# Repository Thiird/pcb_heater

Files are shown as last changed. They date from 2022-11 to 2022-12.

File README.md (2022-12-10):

# PCB Heater

As part of my journey in embedded systems I try to learn new technologies with projects that fix inconveniences in my life. One such inconvenience is that during the winter time, especially in the evening, during long computer-session my feet get terribly cold. So cold that when I finally decide to get up they hurt during the first steps.

To fix this I decided to create a small assembly that houses a plate capable of heating up to a set temperature, on which I can comfortably rest my feet while I'm at my desk.

The assembly consists of three main parts, the heating element, a driver circuit and the wood structure on which everything mounts on.

# Hardware

The heating element is 30x30 cm^2 pcb that features a long copper track that acts as a resistor, and thus heats up when current flows through it.

The pcb is made of three 10x30 cm^2 aluminum pcb connected in series. The reason for using three smaller pcbs instead of a big one, given that the minimum order is 5 units, is that the cost of making five 10x30 cm^2 pcbs is way less than making 5 30x30 cm^2 pcbs. Each single pcb has a resistance of 2 Ohms and has a track 2.64 meters long.

The heating element is powered via a MOSFET used as switch with PWM by an ESP32-S2-MINI-2 MCU. The driver board has an OLED screen and some tactile buttons to let the user set the target temperature and monitor the whole assembly.

The main power source is a 12V-80W AC/DC brick, which feeds the heating PCB and the MCU part of the circuit via a 3.3V switching regulator.

Check bom file for full parts list.

The driver PCB is enclosed in a 3D printed case, which is screwed on the wood assembly.

# Firmware

The firmware for the ESP32 is written with the ESP-IDF framework and runs FreeRTOS.

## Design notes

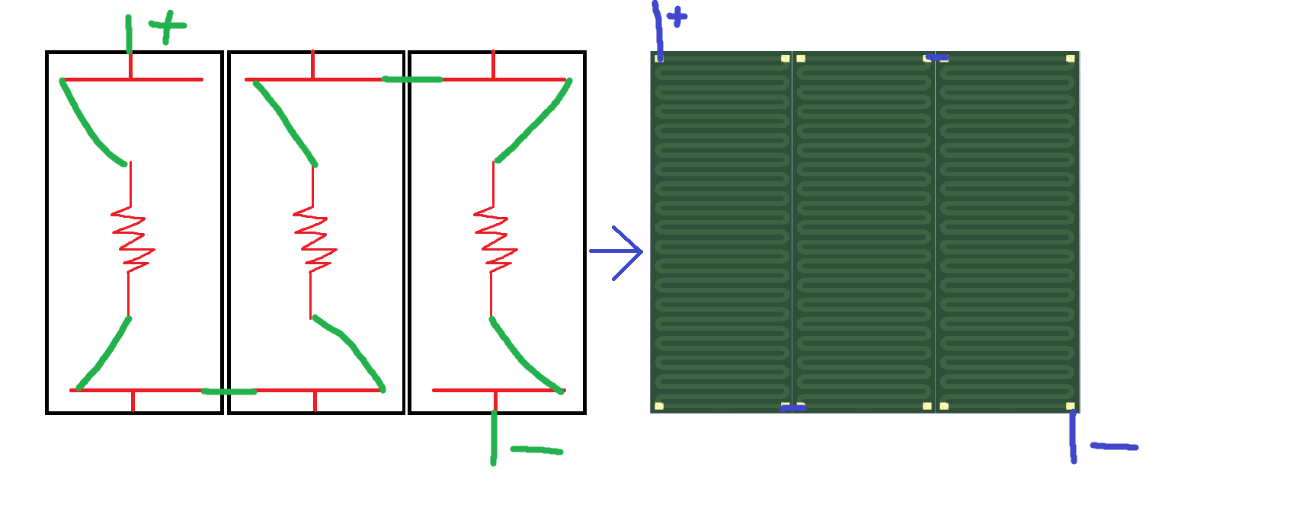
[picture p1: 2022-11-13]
HW/study/heater_schema.png

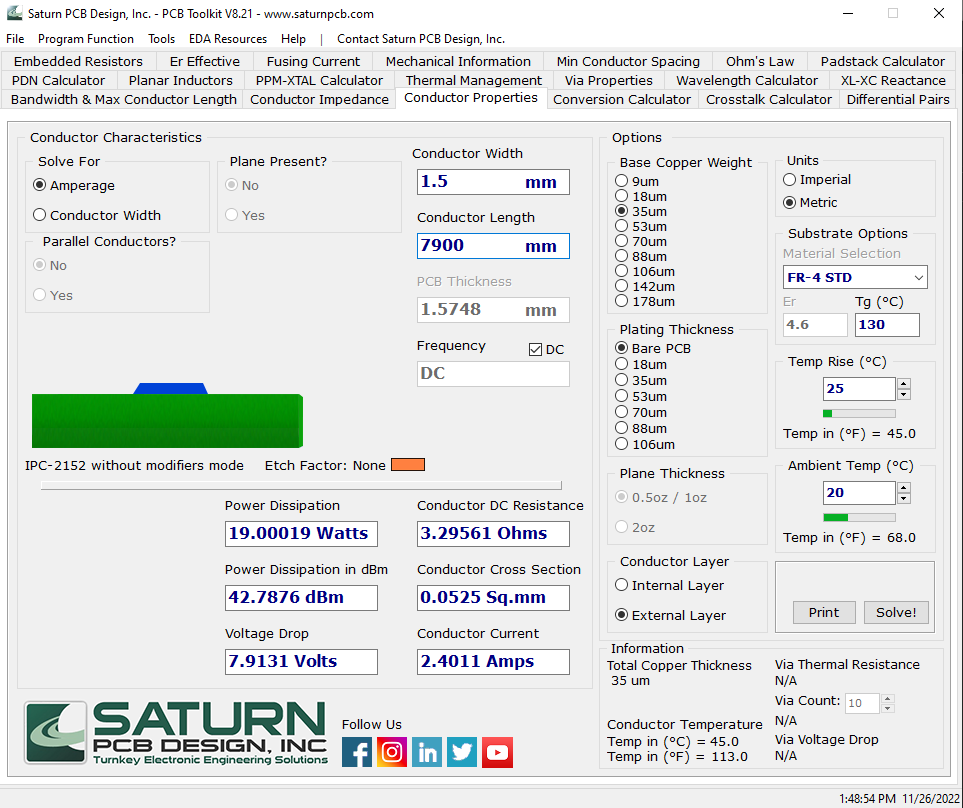
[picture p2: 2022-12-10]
HW/study/simulation.png

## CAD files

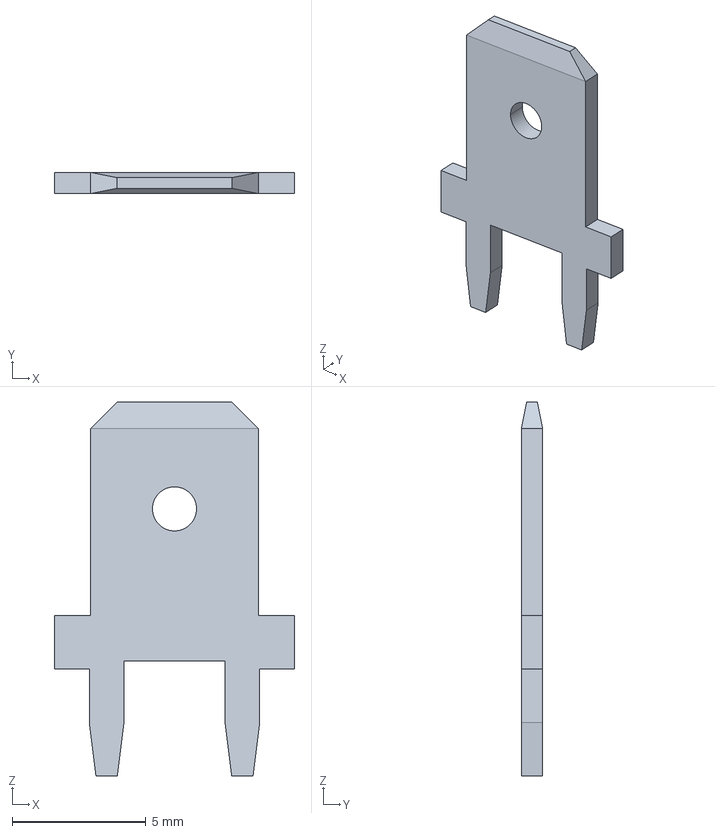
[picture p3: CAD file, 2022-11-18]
HW/footprints/3d/c-2376591-2-a-3d.stp
9.00 x 0.8 x 14.0 mm

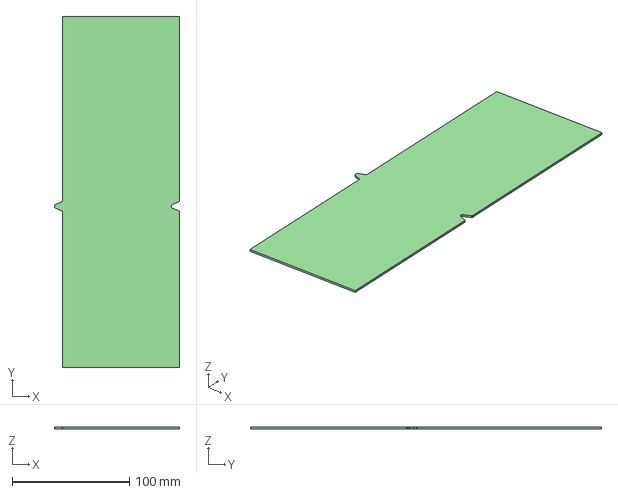
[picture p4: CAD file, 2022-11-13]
HW/pcb_heater_element.step
107.2 x 300.0 x 1.60 mm

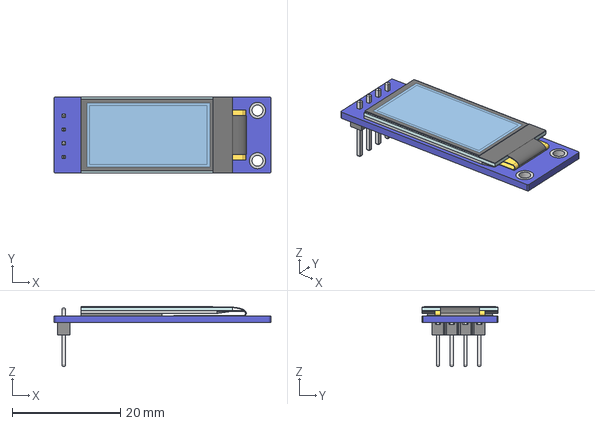
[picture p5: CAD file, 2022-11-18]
HW/footprints/3d/OLED_SSD1312_I2C_0.96.step
40.1 x 14.1 x 11.1 mm

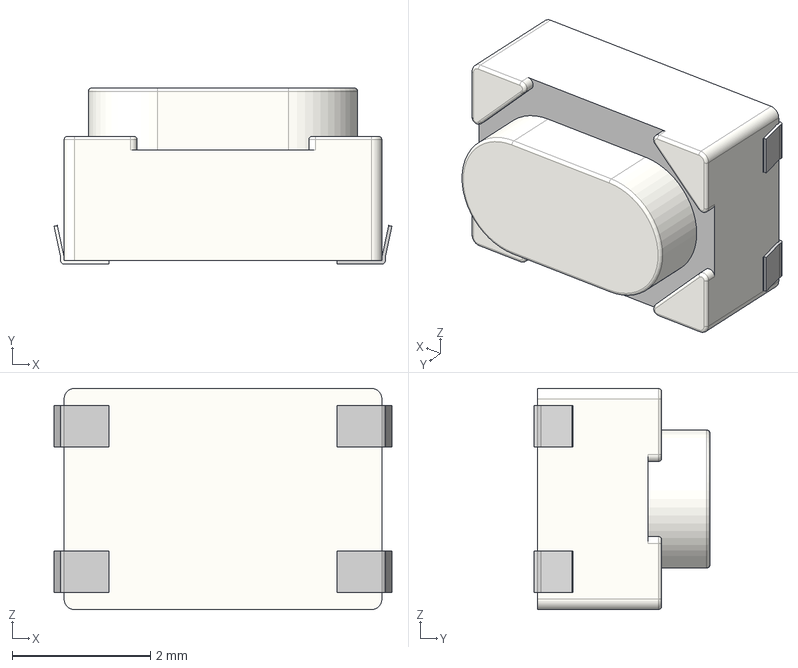
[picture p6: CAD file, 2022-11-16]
HW/footprints/3d/SKRPACE010 v4.step
4.89 x 2.55 x 3.20 mm

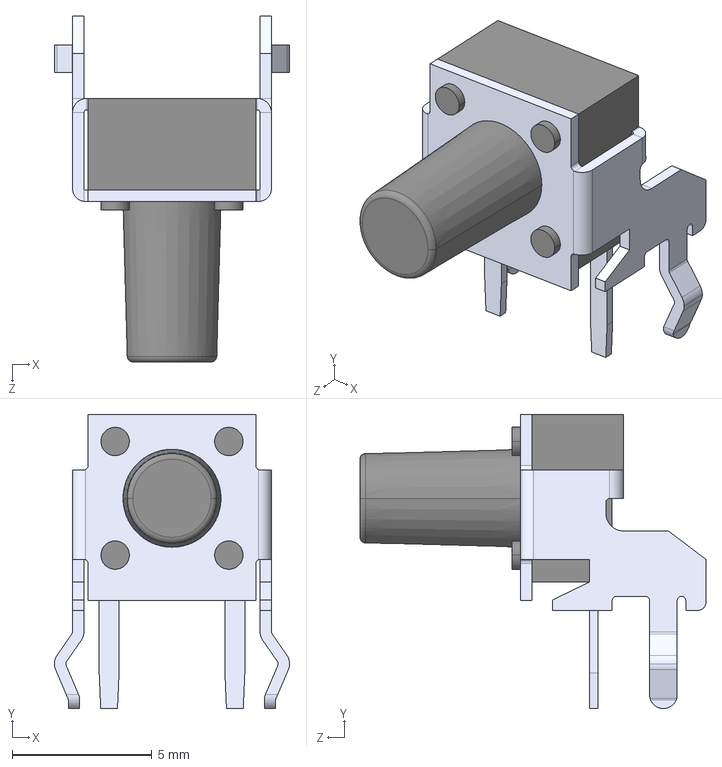
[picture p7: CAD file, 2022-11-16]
HW/footprints/3d/1-1825027-1.step
8.41 x 10.5 x 12.4 mm

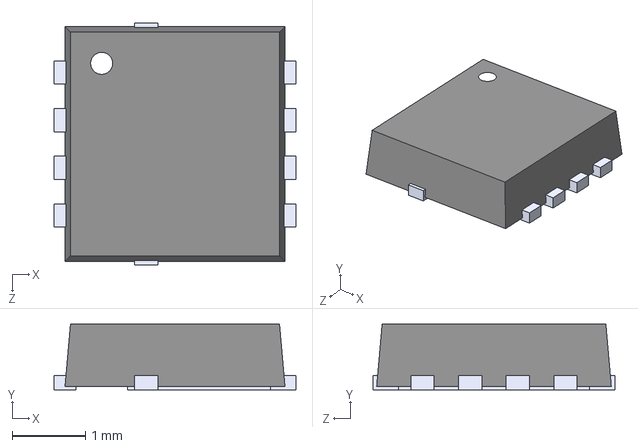
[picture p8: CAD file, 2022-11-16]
HW/footprints/3d/RQ3E100GNTB.step
3.30 x 0.9 x 3.30 mm

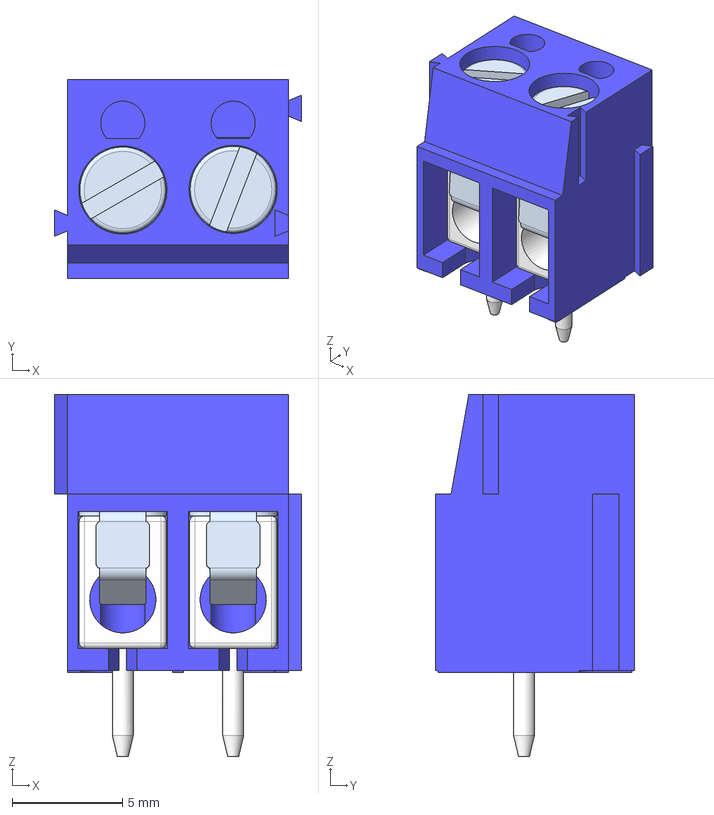
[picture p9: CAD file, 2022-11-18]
HW/footprints/3d/691101710002 (rev1).stp
11.2 x 9.00 x 16.4 mm
Insulator_2
Wire guard x 2
Screw x 2
Pin x 2

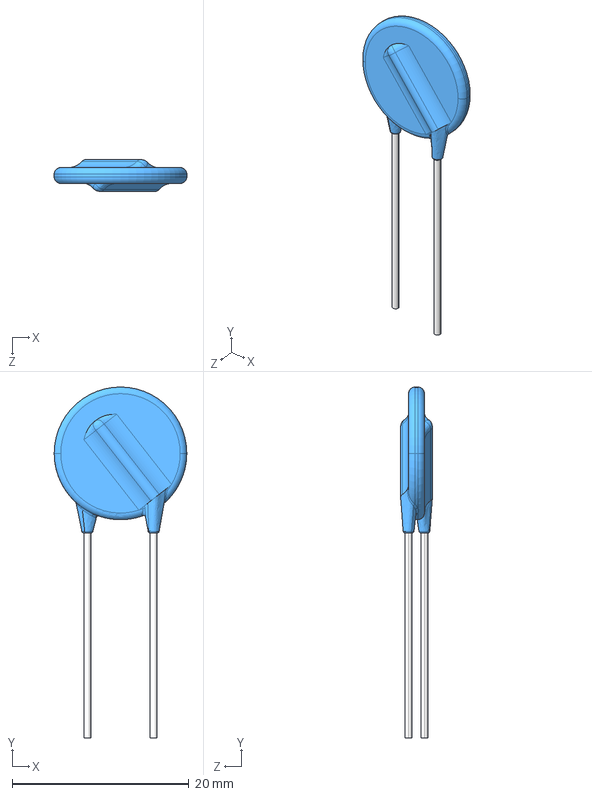
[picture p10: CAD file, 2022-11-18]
HW/footprints/3d/B72214S0351K101.stp
15.0 x 39.7 x 3.60 mm

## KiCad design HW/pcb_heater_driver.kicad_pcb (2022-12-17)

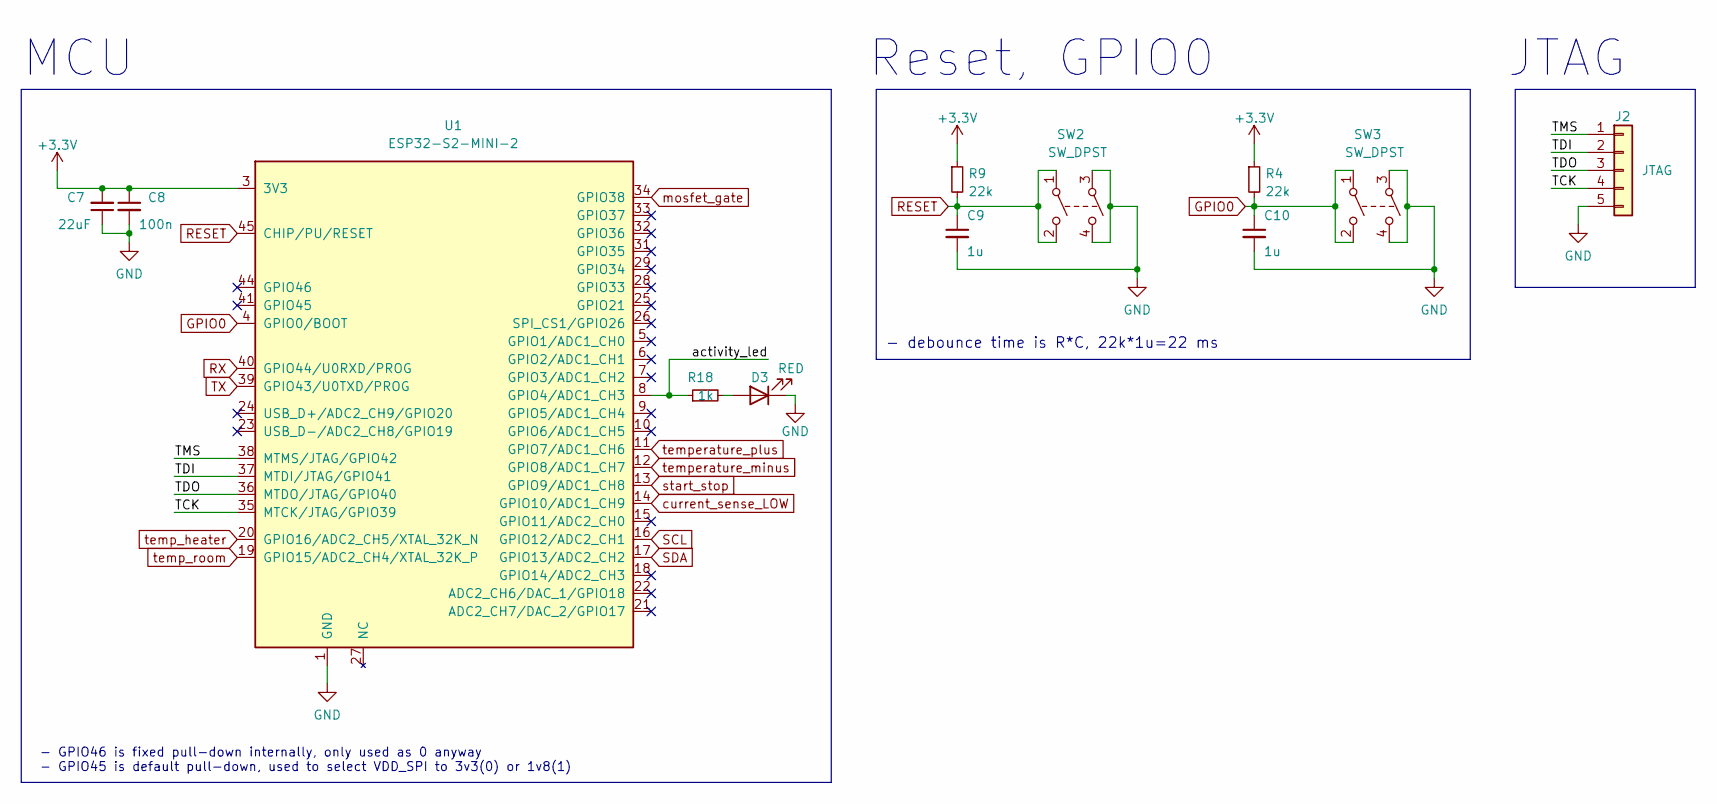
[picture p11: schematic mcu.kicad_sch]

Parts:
C7: 22uF; C_0603_1608Metric
C8: 100n; C_0603_1608Metric
C9, C10: 1u; C_0603_1608Metric
D3: RED; LED_0603_1608Metric
J2: JTAG; PinHeader_1x05_P2.54mm_Vertical
R4, R9: 22k; R_0603_1608Metric
R18: 1k; R_0603_1608Metric
SW2, SW3: SW_DPST; SW_SKRPACE010
U1: ESP32-S2-MINI-2; ESP32-S2-MINI-1

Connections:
/MCU/TCK: J2.4, U1.35 (MTCK/JTAG/GPIO39)
/MCU/TDI: J2.2, U1.37 (MTDI/JTAG/GPIO41)
/MCU/TDO: J2.3, U1.36 (MTDO/JTAG/GPIO40)
/MCU/TMS: J2.1, U1.38 (MTMS/JTAG/GPIO42)
/MCU/activity_led: R18.1, U1.8 (GPIO4/ADC1_CH3)
GND: C7.1, C8.2, C9.2, C10.2, D3.1 (K), J2.5, SW2.3, SW2.4, SW3.3, SW3.4, U1.1 (GND), U1.2 (GND), U1.30 (GND), U1.42 (GND), U1.43 (GND), U1.46 (GND), U1.47 (GND), U1.48 (GND), U1.49 (GND), U1.50 (GND), U1.51 (GND), U1.52 (GND), U1.53 (GND), U1.54 (GND), U1.55 (GND), U1.56 (GND), U1.57 (GND), U1.58 (GND), U1.59 (GND), U1.60 (GND), U1.61 (GND), U1.62 (GND), U1.63 (GND), U1.64 (GND), U1.65 (GND); also elsewhere on the board
GPIO0: C10.1, R4.2, SW3.1, SW3.2, U1.4 (GPIO0/BOOT); also elsewhere on the board
unnamed: D3.2 (A), R18.2
RESET: C9.1, R9.2, SW2.1, SW2.2, U1.45 (CHIP/PU/RESET); also elsewhere on the board
RX: U1.40 (GPIO44/U0RXD/PROG); also elsewhere on the board
SCL: U1.16 (GPIO12/ADC2_CH1); also elsewhere on the board
SDA: U1.17 (GPIO13/ADC2_CH2); also elsewhere on the board
TX: U1.39 (GPIO43/U0TXD/PROG); also elsewhere on the board
current_sense_LOW: U1.14 (GPIO10/ADC1_CH9); also elsewhere on the board
mosfet_gate: U1.34 (GPIO38); also elsewhere on the board
start_stop: U1.13 (GPIO9/ADC1_CH8); also elsewhere on the board
temp_heater: U1.20 (GPIO16/ADC2_CH5/XTAL_32K_N); also elsewhere on the board
temp_room: U1.19 (GPIO15/ADC2_CH4/XTAL_32K_P); also elsewhere on the board
temperature_minus: U1.12 (GPIO8/ADC1_CH7); also elsewhere on the board
temperature_plus: U1.11 (GPIO7/ADC1_CH6); also elsewhere on the board

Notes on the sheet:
Reset, GPIO0
JTAG
- debounce time is R*C, 22k*1u=22 ms
- GPIO46 is fixed pull-down internally, only used as 0 anyway - GPIO45 is default pull-down, used to select VDD_SPI to 3v3(0) or 1v8(1)
MCU

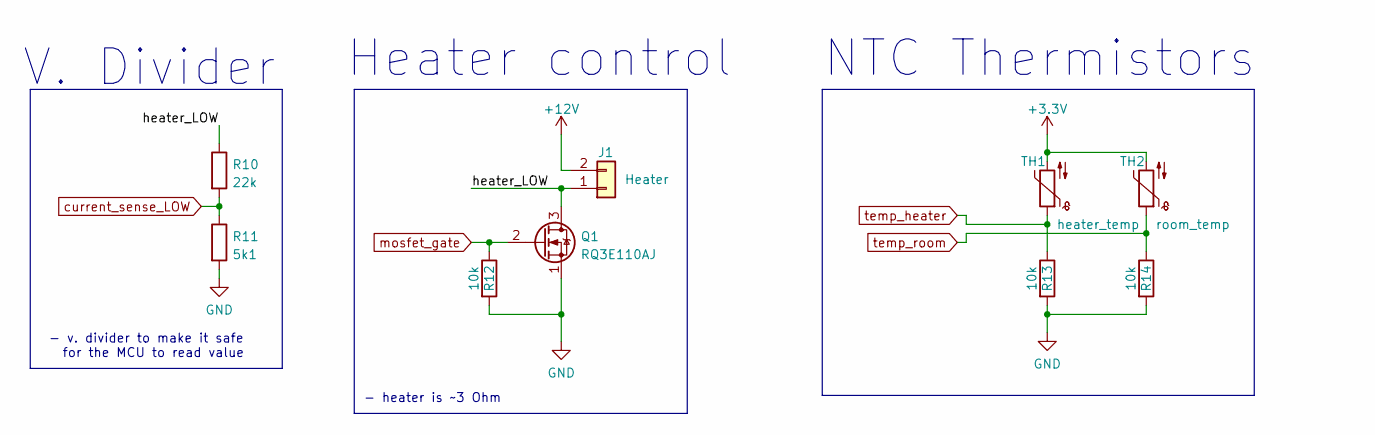
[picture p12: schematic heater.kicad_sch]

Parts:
J1: Heater; WR_TBL_Series_101
Q1: RQ3E110AJ; SOTFL65P330X80-8N
R10: 22k; R_0603_1608Metric
R11: 5k1; R_0603_1608Metric
R12, R13, R14: 10k; R_0603_1608Metric
TH1: heater_temp; SolderJumper-2_P1.3mm_Open_RoundedPad1.0x1.5mm
TH2: room_temp; SolderJumper-2_P1.3mm_Open_RoundedPad1.0x1.5mm

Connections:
+12V: J1.2; also elsewhere on the board
/Heater/heater_LOW: J1.1, Q1.3 (D), R10.1
GND: Q1.1 (S), R11.2, R12.2, R13.2, R14.2; also elsewhere on the board
current_sense_LOW: R10.2, R11.1; also elsewhere on the board
mosfet_gate: Q1.2 (G), R12.1; also elsewhere on the board
temp_heater: R13.1, TH1.1; also elsewhere on the board
temp_room: R14.1, TH2.1; also elsewhere on the board

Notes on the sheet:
V. Divider
NTC Thermistors
- heater is ~3 Ohm
- v. divider to make it safe for the MCU to read value
Heater control

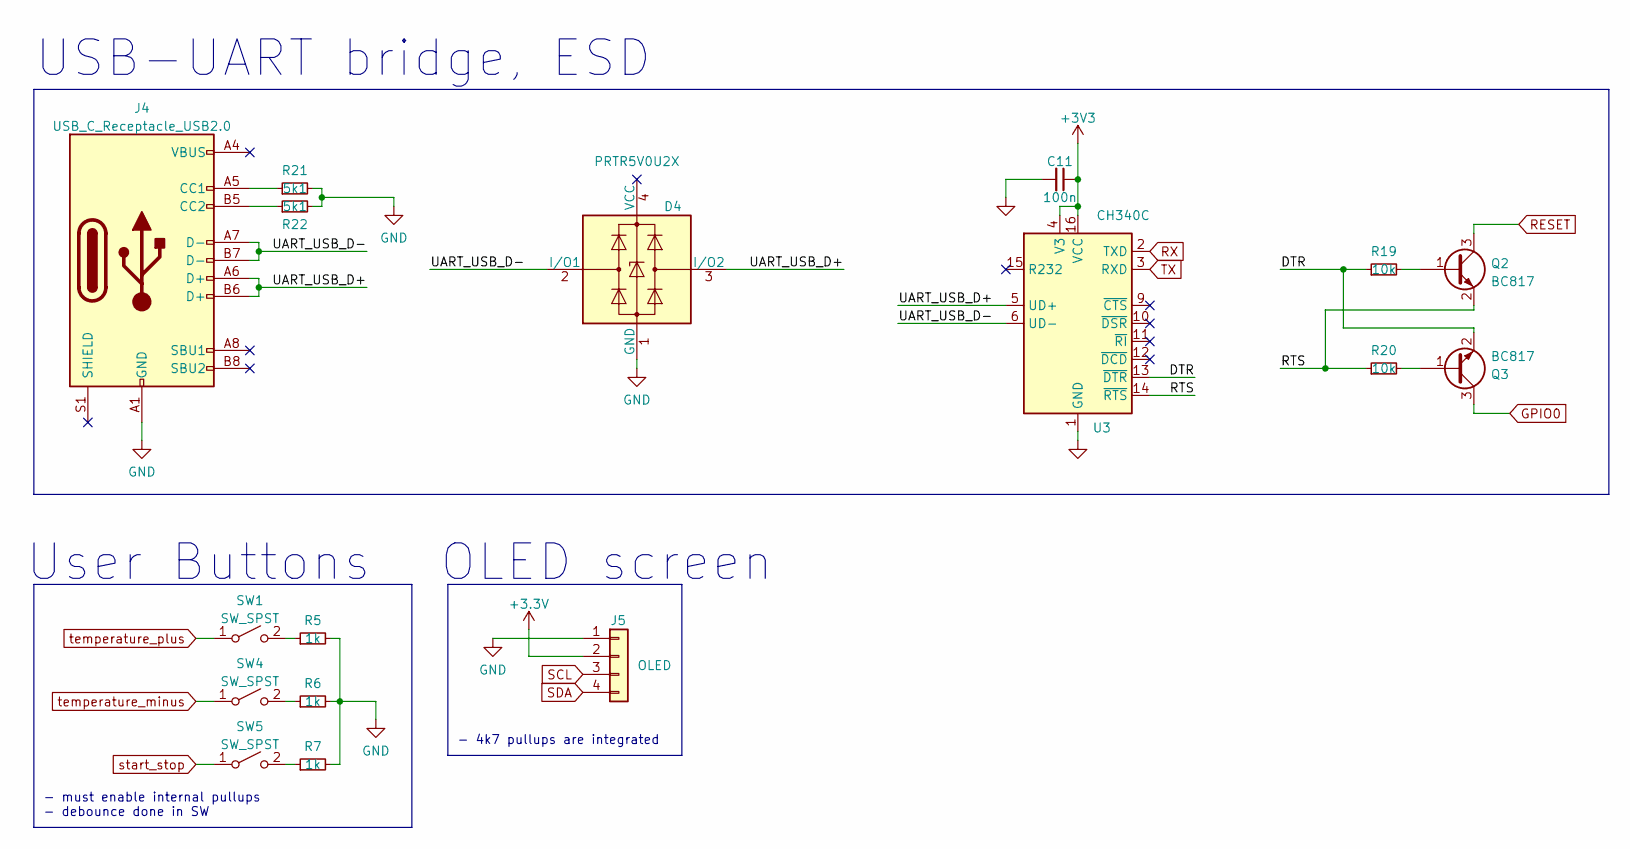
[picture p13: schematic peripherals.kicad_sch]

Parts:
C11: 100n; C_0603_1608Metric
D4: PRTR5V0U2X; SOT-143
J4: USB_C_Receptacle_USB2.0; USB_C_Receptacle_HRO_TYPE-C-31-M-12
J5: OLED; oled_angled
Q2, Q3: BC817; SOT-23
R5, R6, R7: 1k; R_0603_1608Metric
R19, R20: 10k; R_0603_1608Metric
R21, R22: 5k1; R_0603_1608Metric
SW1, SW4, SW5: SW_SPST; SW_1-1825027-1
U3: CH340C; SOIC-16_3.9x9.9mm_P1.27mm

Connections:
/Peripherals/DTR: Q3.2 (E), R19.1, U3.13 (~DTR)
/Peripherals/RTS: Q2.2 (E), R20.1, U3.14 (~RTS)
/Peripherals/UART_USB_D+: D4.3 (I/O2), J4.A6 (D+), J4.B6 (D+), U3.5 (UD+)
/Peripherals/UART_USB_D-: D4.2 (I/O1), J4.A7 (D-), J4.B7 (D-), U3.6 (UD-)
GND: C11.2, D4.1 (GND), J4.A1 (GND), J4.A12 (GND), J4.B1 (GND), J4.B12 (GND), J5.1, R5.2, R6.2, R7.2, R21.2, R22.2, U3.1 (GND); also elsewhere on the board
GPIO0: Q3.3 (C); also elsewhere on the board
unnamed: J4.A5 (CC1), R21.1
unnamed: J4.B5 (CC2), R22.1
unnamed: Q2.1 (B), R19.2
unnamed: Q3.1 (B), R20.2
unnamed: R5.1, SW1.2 (B)
unnamed: R6.1, SW4.2 (B)
unnamed: R7.1, SW5.2 (B)
RESET: Q2.3 (C); also elsewhere on the board
RX: U3.2 (TXD); also elsewhere on the board
SCL: J5.3; also elsewhere on the board
SDA: J5.4; also elsewhere on the board
TX: U3.3 (RXD); also elsewhere on the board
start_stop: SW5.1 (A); also elsewhere on the board
temperature_minus: SW4.1 (A); also elsewhere on the board
temperature_plus: SW1.1 (A); also elsewhere on the board

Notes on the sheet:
- 4k7 pullups are integrated
User Buttons
OLED screen
USB-UART bridge, ESD
- must enable internal pullups - debounce done in SW

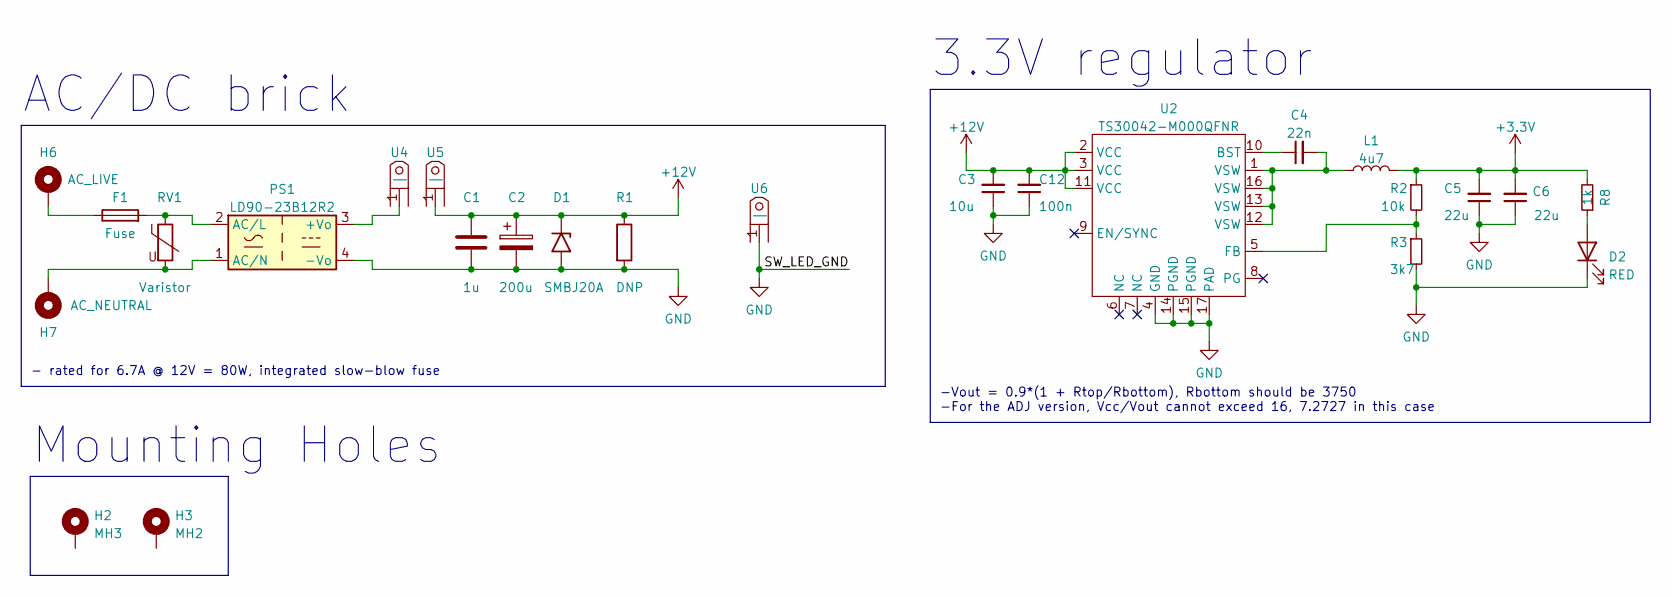
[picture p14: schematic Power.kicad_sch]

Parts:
C1: 1u; C_1206_3216Metric; rating 100V
C2: 200u; CP_Radial_D10.0mm_P5.00mm; rating 35V
C3: 10u; C_0603_1608Metric; rating 50V
C4: 22n; C_0603_1608Metric
C5, C6: 22u; C_0603_1608Metric
C12: 100n; C_0603_1608Metric; rating 50V
D1: SMBJ20A; D_SMB
D2: RED; LED_0603_1608Metric
F1: Fuse; 3622
H2: MH3; MountingHole_3.2mm_M3_Pad_TopBottom
H3: MH2; MountingHole_3.2mm_M3_Pad_TopBottom
H6: AC_LIVE; MountingHole_2.2mm_M2_Pad_TopBottom
H7: AC_NEUTRAL; MountingHole_2.2mm_M2_Pad_TopBottom
L1: 4u7; BWVS005050404R7M00
PS1: LD90-23B12R2
R1: DNP; R_2010_5025Metric
R2: 10k; R_0603_1608Metric
R3: 3k7; R_0603_1608Metric
R8: 1k; R_0603_1608Metric
RV1: Varistor; B72214S0351K101
U2: TS30042-M000QFNR; QFN-16-1EP_3x3mm_P0.5mm_EP1.75x1.75mm_ThermalVias
U4, U5, U6: fork_p5.0mm

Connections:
+12V: C1.1, C2.1, C3.2, C12.2, D1.1 (A1), R1.1, U2.2 (VCC), U2.3 (VCC), U2.11 (VCC), U5.1 (|); also elsewhere on the board
GND: C1.2, C2.2, C3.1, C5.1, C6.1, C12.1, D1.2 (A2), D2.1 (K), PS1.4 (-Vo), R1.2, R3.2, U2.4 (GND), U2.14 (PGND), U2.15 (PGND), U2.17 (PAD), U6.1 (|); also elsewhere on the board
unnamed: C4.1, U2.10 (BST)
unnamed: C4.2, L1.1, U2.1 (VSW), U2.12 (VSW), U2.13 (VSW), U2.16 (VSW)
unnamed: D2.2 (A), R8.1
unnamed: F1.1, H6.1
unnamed: F1.2, PS1.2 (AC/L), RV1.1
unnamed: H7.1, PS1.1 (AC/N), RV1.2
unnamed: PS1.3 (+Vo), U4.1 (|)
unnamed: R2.2, R3.1, U2.5 (FB)

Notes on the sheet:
AC/DC brick
Mounting Holes
- rated for 6.7A @ 12V = 80W, integrated slow-blow fuse
-Vout = 0.9*(1 + Rtop/Rbottom), Rbottom should be 3750 -For the ADJ version, Vcc/Vout cannot exceed 16, 7.2727 in this case
3.3V regulator

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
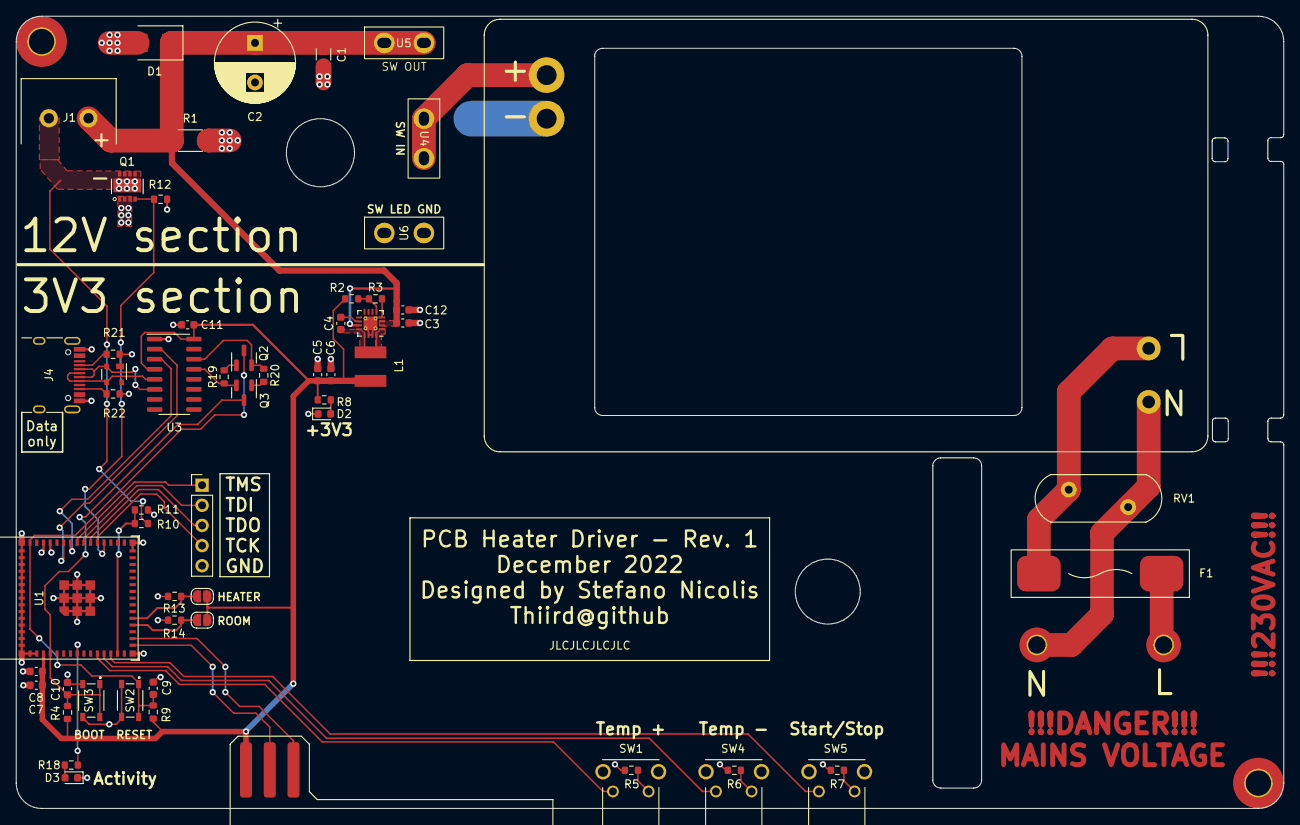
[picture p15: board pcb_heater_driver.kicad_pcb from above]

Board: 2 copper layers, 160.0 x 100.0 mm, 63 parts (0 on the bottom side), 42 nets.

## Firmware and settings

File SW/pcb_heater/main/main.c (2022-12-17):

#include <stdio.h>
#include "freertos/FreeRTOS.h"
#include "freertos/task.h"
#include "esp_log.h"
#include "esp_intr_alloc.h"
#include "driver/gpio.h"
#include "driver/uart.h"
#include "driver/ledc.h"
#include "driver/i2c.h"
#include "hal/uart_types.h"
#include "hal/adc_types.h"
#include "esp_adc/adc_oneshot.h"
#include "ssd1306.h"
#include "math.h"

#define ACTIVITY_LED GPIO_NUM_4        // GPIO4, activity led, active high
#define TEMP_INC_BTN GPIO_NUM_7        // GPIO7, increase target temperature, active low
#define TEMP_DEC_BTN GPIO_NUM_8        // GPIO8, decrease target temperature, active low
#define START_STOP_BTN GPIO_NUM_9      // GPIO9, start/stop heating, active low
#define HEATER_MOSFET_GATE GPIO_NUM_38 // GPIO38
#define MAX_ALLOWED_TEMP 55            // °C
#define ADC_RESOLUTION ADC_BITWIDTH_13
#define ADC_MAX_VALUE 8191.0
#define LEDC_MODE LEDC_LOW_SPEED_MODE
#define LEDC_CHANNEL LEDC_CHANNEL_0
#define LEDC_DUTY_RES LEDC_TIMER_13_BIT
#define LEDC_DUTY_RES_ACTUAL 8192 // 2 ^ 13
#define LEDC_FREQ 1000            // 1KHz

#define I2C_SDA 13           // GPIO13
#define I2C_SCL 12           // GPIO12
#define I2C_FREQUENCY 100000 // 100 Kb/s
#define I2C_USED_PORT I2C_NUM_0

#define ONE_SECOND 1000 / portTICK_PERIOD_MS
#define DEBOUNCE_TIME_MS 200 / portTICK_PERIOD_MS // 0.2 s debounce time

#define HEATER_RESISTANCE 3.4        // @ 20°C
#define NTC_BETA 3936.0              // 20°/25° C
#define NTC_ROOM_RESISTANCE 8500.0   // 10k Ohm @ 25°C, 8.5k Ohm @ 20°C
#define NTC_BALANCE_RESISTOR 10000.0 // 10k Ohm
#define ROOM_TEMP 293.15             // 20° C
#define NTC_SAMPLE_NUMBER 5

float heater_current_I = 0;
float heater_voltage_low_side = 0;
float heater_temp_F = 0;
float heater_temp_C = 0;
int8_t heater_target_temp_C = 20;
bool is_heating_active = false;
float room_temp_F = 0;
float room_temp_C = 0;
int8_t mosfet_duty_cycle = 0;

uint32_t temp_inc_btn_ms = 0;
uint32_t temp_dec_btn_ms = 0;
uint32_t start_stop_btn_ms = 0;

adc_oneshot_unit_handle_t adc2_handle = NULL;
int adcTempVal = 0;
int adcIVal = 0;

adc_oneshot_unit_handle_t adc1_handle = NULL;

static QueueHandle_t gpio_evt_queue = NULL;
static ssd1306_handle_t ssd1306 = NULL;

static void IRAM_ATTR gpio_isr_handler(void *arg)
{
    uint32_t gpio_num = (uint32_t)arg;
    xQueueSendFromISR(gpio_evt_queue, &gpio_num, NULL);
}

void update_duty_cycle()
{
    // duty cycle formula is ((2 ^ bit_res) - 1) * desired_duty_cycle

    // Set new duty cycle
    ESP_ERROR_CHECK(ledc_set_duty(LEDC_MODE, LEDC_CHANNEL, (uint32_t)((LEDC_DUTY_RES_ACTUAL - 1) * (mosfet_duty_cycle / 100.0))));
    // Update duty cycle
    ESP_ERROR_CHECK(ledc_update_duty(LEDC_MODE, LEDC_CHANNEL));

    printf("Duty cycle: %d = %ld\n", mosfet_duty_cycle, (uint32_t)((LEDC_DUTY_RES_ACTUAL - 1) * (mosfet_duty_cycle / 100.0)));
    printf("value in percent is %f\n", (mosfet_duty_cycle / 100.0));
}

void read_heater_current()
{
    /*
     Current sense circuit is    +12V--2Ohm Heater--22kOhm--10kOhm--GND
     which can be aproximated to +12V---------------22kOhm--10kOhm--GND
     V. divider is used to bring the voltage level after the heater to
     a safe range for the ESP32-S2 ADC.
    */

    adcIVal = 0;
    adc_oneshot_read(adc2_handle, ADC_CHANNEL_3, &adcIVal);

    // adcValue/ADC resolution * Vref * (required resistor/choosen resistor)
    heater_voltage_low_side = adcIVal / (2 ^ ADC_RESOLUTION) * 12;

    // I = V / R
    heater_current_I = heater_voltage_low_side * 2;
}

void read_heater_temp()
{
    // Reference: https://www.jameco.com/Jameco/workshop/TechTip/temperature-measurement-ntc-thermistors.html

    adc_oneshot_read(adc2_handle, ADC_CHANNEL_4, &adcTempVal);
    /*
     NTC thermistor config: +3V3---NTC---10kOhm---GND
     Usual v. divider equation is Vout = Vs * (R0 / ( Rt + R0 ))
     Rearrange to find NTC resistance: Rt = R0 * (( Vs / Vout ) - 1)
     In our case the ADC's Vref is equal to the Vin of the V. divider
     so we can say: adcMax / adcTempVal = Vref / Vout
     With this we can simplify to Rt = R0 * ((adcMax / adcTempVal) - 1)
     ADC on ESP32-S2 is 12-bit, so adcMax is 4095
     */
    heater_temp_F = 10000 * ((4095 / adcTempVal) - 1);

    // Fahrenheit --> Celsius
    heater_temp_C = (heater_temp_F - 32) / 1.8;
}

void isr_change_heater_target_temp(uint8_t value)
{
    if (value)
    {
        mosfet_duty_cycle++;
        if (heater_target_temp_C < MAX_ALLOWED_TEMP)
        {
            heater_target_temp_C++;
        }
        return;
    }

    mosfet_duty_cycle--;

    if (mosfet_duty_cycle > 100)
    {
        mosfet_duty_cycle = 100;
    }

    if (mosfet_duty_cycle < 0)
    {
        mosfet_duty_cycle = 0;
    }

    if (heater_target_temp_C > 0)
    {
        heater_target_temp_C--;
    }
}

void isr_start_stop_heating()
{
    is_heating_active = !is_heating_active;
}

void vTaskUserButtonsListener(void *arg)
{
    uint32_t io_num = -1;
    while (true)
    {
        if (xQueueReceive(gpio_evt_queue, &io_num, portMAX_DELAY))
        {
            if (io_num == TEMP_INC_BTN)
            {
                if ((xTaskGetTickCount() - temp_inc_btn_ms) > DEBOUNCE_TIME_MS)
                {
                    printf("Button event: Temperature Increase\n");
                    mosfet_duty_cycle = (mosfet_duty_cycle != 100) ? mosfet_duty_cycle + 5 : 100;
                    update_duty_cycle();
                    temp_inc_btn_ms = xTaskGetTickCount();
                }
            }

            if (io_num == TEMP_DEC_BTN)
            {
                if ((xTaskGetTickCount() - temp_dec_btn_ms) > DEBOUNCE_TIME_MS)
                {
                    printf("Button event: Temperature Decrease\n");
                    mosfet_duty_cycle = mosfet_duty_cycle == 0 ? 0 : mosfet_duty_cycle - 5;
                    update_duty_cycle();
                    temp_dec_btn_ms = xTaskGetTickCount();
                }
            }

            if (io_num == START_STOP_BTN)
            {
                if ((xTaskGetTickCount() - start_stop_btn_ms) > DEBOUNCE_TIME_MS)
                {
                    mosfet_duty_cycle = 0;
                    update_duty_cycle();
                    printf("Duty cycle is now %d\n", mosfet_duty_cycle);
                    printf("Button event: Start/Stop\n");
                    start_stop_btn_ms = xTaskGetTickCount();
                }
            }
        }
    }
}

void vReadHeaterCurrent()
{
    while (true)
    {
        adc_oneshot_read(adc1_handle, ADC_CHANNEL_9, &adcIVal);

        float voltage = (adcIVal / 8192.0) * 12;
        float current = voltage / HEATER_RESISTANCE;
        printf("Heater voltage %.2f V, current %.2f A\n", voltage, current);

        vTaskDelay(ONE_SECOND);
    }
}

void sample_ntc_temperature(adc_oneshot_unit_handle_t adc_handle, int adc_channel, float *temperature_F, float *temperature_C)
{ // https://www.digikey.com/en/maker/projects/how-to-measure-temperature-with-an-ntc-thermistor/4a4b326095f144029df7f2eca589ca54

    // Take sample
    int adcSamples[NTC_SAMPLE_NUMBER];
    for (int i = 0; i < NTC_SAMPLE_NUMBER; i++)
        adc_oneshot_read(adc_handle, adc_channel, &adcSamples[i]);

    // Average samples
    float adcAverage = 0.0;
    for (int i = 0; i < NTC_SAMPLE_NUMBER; i++)
        adcAverage += adcSamples[i];

    adcAverage /= NTC_SAMPLE_NUMBER;

    if (adcAverage < 100) // NTC disconnected or something else
    {
        (*temperature_F) = 0.0;
        (*temperature_C) = 0.0;
        return;
    }

    float ntc_resistance = NTC_BALANCE_RESISTOR * ((ADC_MAX_VALUE / adcAverage) - 1);

    (*temperature_F) = (NTC_BETA * ROOM_TEMP) /
                       (NTC_BETA + (ROOM_TEMP * log(ntc_resistance / NTC_ROOM_RESISTANCE)));

    (*temperature_C) = (*temperature_F) - 273.15;
}

void vReadHeaterTemperature()
{
    while (true)
    {
        sample_ntc_temperature(adc2_handle, ADC_CHANNEL_4, &heater_temp_F, &heater_temp_C);
        vTaskDelay(ONE_SECOND);

        printf("heater temp is %f \n", heater_temp_C);
    }
}

void vReadRoomTemperature()
{
    while (true)
    {
        sample_ntc_temperature(adc2_handle, ADC_CHANNEL_0, &room_temp_F, &room_temp_C);
        vTaskDelay(ONE_SECOND * 10);
        printf("room temp is %f \n", room_temp_C);
    }
}

void vUpdateOled()
{
    ssd1306 = ssd1306_create(I2C_USED_PORT, SSD1306_I2C_ADDRESS);

    ssd1306_refresh_gram(ssd1306);
    ssd1306_clear_screen(ssd1306, 0x00);

    // char data_str[10] = {0};
    uint32_t cont = 0;
    /*sprintf(data_str, "C STR");
    ssd1306_draw_string(ssd1306, 70, 16, (const uint8_t *)data_str, 16, 1);
    ssd1306_refresh_gram(ssd1306);*/

    while (true)
    {
        ssd1306_fill_rectangle(ssd1306, 0, 0, 60, 30, cont);
        ssd1306_refresh_gram(ssd1306);
        cont = !cont;
        vTaskDelay(ONE_SECOND);
    }
}

esp_err_t init_gpio()
{
    // Activity LED
    gpio_config_t io_conf = {
        io_conf.intr_type = GPIO_INTR_DISABLE,       // disable interrupt
        io_conf.mode = GPIO_MODE_OUTPUT,             // set as output mode
        io_conf.pin_bit_mask = 1ULL << ACTIVITY_LED, // bit mask of the pins that you want to set
        io_conf.pull_down_en = 0,                    // disable pull-down mode
        io_conf.pull_up_en = 0};                     // disable pull-up mode
    ESP_ERROR_CHECK(gpio_config(&io_conf));

    // Increase temp button
    io_conf.intr_type = GPIO_INTR_NEGEDGE;
    io_conf.mode = GPIO_MODE_INPUT;
    io_conf.pin_bit_mask = 1ULL << TEMP_INC_BTN;
    io_conf.pull_down_en = 0;
    io_conf.pull_up_en = 1;
    ESP_ERROR_CHECK(gpio_config(&io_conf));

    // Decrease temp button
    io_conf.intr_type = GPIO_INTR_NEGEDGE;
    io_conf.mode = GPIO_MODE_INPUT;
    io_conf.pin_bit_mask = 1ULL << TEMP_DEC_BTN;
    io_conf.pull_down_en = 0;
    io_conf.pull_up_en = 1;
    ESP_ERROR_CHECK(gpio_config(&io_conf));

    // Start/Stop temp button
    io_conf.intr_type = GPIO_INTR_NEGEDGE;
    io_conf.mode = GPIO_MODE_INPUT;
    io_conf.pin_bit_mask = 1ULL << START_STOP_BTN;
    io_conf.pull_down_en = 0;
    io_conf.pull_up_en = 1;
    ESP_ERROR_CHECK(gpio_config(&io_conf));

    // create a queue to handle gpio event from isr
    gpio_evt_queue = xQueueCreate(10, sizeof(uint32_t));

    // start gpio task
    xTaskCreate(vTaskUserButtonsListener, "gpio_task_example", 2048, NULL, 10, NULL);

    // Enable per-GPIO interrupts
    ESP_ERROR_CHECK(gpio_install_isr_service(ESP_INTR_FLAG_LEVEL1));

    // Hook ISR handler for each button
    ESP_ERROR_CHECK(gpio_isr_handler_add(TEMP_INC_BTN, gpio_isr_handler, (void *)TEMP_INC_BTN));
    ESP_ERROR_CHECK(gpio_isr_handler_add(TEMP_DEC_BTN, gpio_isr_handler, (void *)TEMP_DEC_BTN));
    ESP_ERROR_CHECK(gpio_isr_handler_add(START_STOP_BTN, gpio_isr_handler, (void *)START_STOP_BTN));

    return ESP_OK;
}

esp_err_t init_uart()
{
    // Configure UART parameters
    const uart_port_t uart_num = UART_NUM_1;
    uart_config_t uart_config = {
        .baud_rate = 115200,
        .data_bits = UART_DATA_8_BITS,
        .parity = UART_PARITY_DISABLE,
        .stop_bits = UART_STOP_BITS_1,
        .flow_ctrl = UART_HW_FLOWCTRL_CTS_RTS,
        .rx_flow_ctrl_thresh = 122};
    ESP_ERROR_CHECK(uart_param_config(uart_num, &uart_config));

    // Set UART pins(TX: IO39, RX: IO44, RTS: IO5, CTS: IO6), RTS and CTS not used
    ESP_ERROR_CHECK(uart_set_pin(UART_NUM_0, 39, 44, 5, 6));

    // Setup UART buffered IO with event queue
    const int uart_buffer_size = (1024 * 2);
    QueueHandle_t uart_queue;
    // Install UART driver using an event queue here
    ESP_ERROR_CHECK(uart_driver_install(UART_NUM_0, uart_buffer_size,
                                        uart_buffer_size, 10, &uart_queue, 0));
    return ESP_OK;
}

esp_err_t init_pwm()
{
    // Configure LEDC PWM timer
    ledc_timer_config_t ledc_timer = {
        .speed_mode = LEDC_MODE,
        .timer_num = LEDC_TIMER_0,
        .freq_hz = LEDC_FREQ,
        .duty_resolution = LEDC_DUTY_RES,
        .clk_cfg = LEDC_AUTO_CLK};
    ESP_ERROR_CHECK(ledc_timer_config(&ledc_timer));

    // Configure LEDC PWM channel
    ledc_channel_config_t ledc_channel = {
        .speed_mode = LEDC_LOW_SPEED_MODE,
        .channel = LEDC_CHANNEL,
        .timer_sel = LEDC_TIMER_0,
        .intr_type = LEDC_INTR_DISABLE,
        .gpio_num = HEATER_MOSFET_GATE,
        .duty = 0, // Set duty to 0%
        .hpoint = 0};
    ESP_ERROR_CHECK(ledc_channel_config(&ledc_channel));

    return ESP_OK;
}

esp_err_t init_i2c()
{
    // OLED i2c port
    i2c_config_t conf = {
        .mode = I2C_MODE_MASTER,
        .sda_io_num = I2C_SDA,
        .sda_pullup_en = GPIO_PULLUP_DISABLE, // already on board
        .scl_io_num = I2C_SCL,
        .scl_pullup_en = GPIO_PULLUP_DISABLE, // already on board
        .master.clk_speed = I2C_FREQUENCY,
    };
    ESP_ERROR_CHECK(i2c_param_config(I2C_USED_PORT, &conf));

    ESP_ERROR_CHECK(i2c_driver_install(I2C_USED_PORT, I2C_MODE_MASTER, 0, 0, 0));

    return ESP_OK;
}

esp_err_t init_adc()
{
    // Configure ADC2 instance
    adc_oneshot_unit_init_cfg_t adc2_config = {
        .unit_id = ADC_UNIT_2,
        .ulp_mode = ADC_ULP_MODE_DISABLE,
    };
    ESP_ERROR_CHECK(adc_oneshot_new_unit(&adc2_config, &adc2_handle));

    // Create config for ADC channel
    adc_oneshot_chan_cfg_t config2 = {
        .bitwidth = ADC_RESOLUTION,
        .atten = ADC_ATTEN_DB_11,
    };

    // Apply config to Channe3-ADC2, room temp
    ESP_ERROR_CHECK(adc_oneshot_config_channel(adc2_handle, ADC_CHANNEL_3, &config2));

    // Apply config to Channe4-ADC2, heater temp
    ESP_ERROR_CHECK(adc_oneshot_config_channel(adc2_handle, ADC_CHANNEL_4, &config2));

    // Configure ADC1 instance
    adc_oneshot_unit_init_cfg_t adc1_config = {
        .unit_id = ADC_UNIT_1,
        .ulp_mode = ADC_ULP_MODE_DISABLE,
    };
    ESP_ERROR_CHECK(adc_oneshot_new_unit(&adc1_config, &adc1_handle));

    // Create config for ADC channel
    adc_oneshot_chan_cfg_t config1 = {
        .bitwidth = ADC_RESOLUTION, // can't use 13 bits, bit 1 always 0, see errata
        .atten = ADC_ATTEN_DB_11,
    };

    // Apply config to Channe9-ADC1, heater current
    ESP_ERROR_CHECK(adc_oneshot_config_channel(adc1_handle, ADC_CHANNEL_9, &config1));

    return ESP_OK;
}

void vTaskActivityLed()
{
    while (true)
    {
        gpio_set_level(ACTIVITY_LED, 1);
        vTaskDelay(ONE_SECOND);
        gpio_set_level(ACTIVITY_LED, 0);
        vTaskDelay(ONE_SECOND);
    }
}

void app_main(void)
{
    // init_uart();

    init_gpio();
    init_adc();
    init_pwm();
    init_i2c();

    xTaskCreate(vTaskActivityLed, "blink activity led", 2048, NULL, 5, NULL);
    xTaskCreate(vTaskUserButtonsListener, "user buttons listener", 2048, NULL, 5, NULL);
    xTaskCreate(vUpdateOled, "update oled", 2048, NULL, 5, NULL);
    // xTaskCreate(vReadHeaterCurrent, "read heater current", 2048, NULL, 10, NULL);
    // xTaskCreate(vReadHeaterTemperature, "read heater temp", 2048, NULL, 10, NULL);
    xTaskCreate(vReadRoomTemperature, "read room temp", 2048, NULL, 10, NULL);
}

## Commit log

2022-11-12 Initial commit, will I do this?
    [pcb_heater-B_Cu.gbr, pcb_heater-B_Mask.gbr, pcb_heater-B_Paste.gbr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]
2022-11-13 Lots of progress on heater PCB and links
    [pcb_heater-B_Cu.gbr, pcb_heater-B_Mask.gbr, pcb_heater-B_Paste.gbr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]
2022-11-14 Sectioned schematic, reqorked heater trace length and thickness
    [Power.kicad_sch, heater.kicad_sch, mcu.kicad_sch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]
2022-11-15 Fixed board, big work in schematic, to finish
    [Power.kicad_sch, heater.kicad_sch, mcu.kicad_sch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]
2022-11-16 Finished sch, to be checked. Initial components layout
    [1-1825027-1.step, Power.kicad_sch, RQ3E100GNTB.step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]
2022-11-16 Sch finalized, added EMC stuff, user buttons and oled
    [Power.kicad_sch, heater.kicad_sch, mcu.kicad_sch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]
2022-11-18 Work on layout, sch fixes, added several 3d models
    [691101710002 (rev1).stp, B72214S0351K101.stp, OLED_SSD1312_I2C_0.96.step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]
2022-11-18 starterd routing, removed OTG usb port
    [Power.kicad_sch, heater.kicad_sch, mcu.kicad_sch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]
2022-11-19 Finished routing, only mosfet left, fixed layout, outline
    [Power.kicad_sch, mcu.kicad_sch, pcb_heater_driver.kicad_pcb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]
2022-11-20 Fix board, QOL fixes
    [heater.kicad_sch, mcu.kicad_sch, pcb_heater_driver.kicad_pcb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]
2022-11-24 QOL changes on pcb, fixed wrong ACDC brick polarity xD
    [Power.kicad_sch, heater.kicad_sch, mcu.kicad_sch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]
2022-11-25 revision 0
    [Power.kicad_sch, heater.kicad_sch, mcu.kicad_sch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]
2022-12-04 Added uart and gpio init, basic main
2022-12-04 Addede ISRs for user buttons, functions templates
2022-12-08 Readme and board fixes
    [pcb_heater_driver.kicad_pcb, pcb_heater_element.kicad_pcb]
2022-12-09 Added i2c init and write
2022-12-10 Started SSD1306 oled driver
2022-12-10 i2c and ssd1306 refactor
2022-12-10 More ssd1306 work, implemented pwm for mosfet driving
2022-12-15 First flash, code tidy up, buttons debounce, oled test
2022-12-15 Fixed silkscreen, removed one thermistor, fixed component placement
    [Power.kicad_sch, heater.kicad_sch, mcu.kicad_sch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]
2022-12-15 Fixed buttons debounce, fixed i2c
    [main.c]
2022-12-16 Fixed adc, fixed pwm, first test run succesful!
    [main.c]
2022-12-16 Fixed component placement, enlarged some pcb slots, removed two thermistors
    [heater.kicad_sch, mcu.kicad_sch, pcb_heater_driver.kicad_pcb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]
